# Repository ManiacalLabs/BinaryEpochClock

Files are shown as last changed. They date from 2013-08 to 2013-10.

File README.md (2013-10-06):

BinaryEpochClock
================

**THIS MAY NOT BE THE FIRMWARE THAT CAME WITH YOUR CLOCK**

*We are constantly working on improving the firmware of our kits and the firmware contained in this repository may not be the same as that which came pre-programmed on your Binary Epoch Clock Kit.*

There are a few improvements over the original v1.0 Firmware

- Based on changes suggested by [kredal](https://github.com/kredal/) there is an alternte clock face to make the clock face a little more readable. Use the following key to make it a little easier to read: http://maniacallabs.com/misc/Binary_Clock_Key.png
- A 1D Pong face is now included - It is not playable, just sit back and enjoy the game.
- Short press A in order to switch between the three clock faces

The Binary Epoch Clock is a new twist on the old binary clock idea. Instead of just showing the individual digits as binary values, it show [Unix Epoch](http://en.wikipedia.org/wiki/Unix_Epoch) time as a full 32-bit binary value. This unique timepiece will make a great addition to the desk of any computer, electronics, time, or binary geek.

It runs off of an ATMega328P which makes is both fully compatible with the Arduino IDE and easily hackable. Also built in is a DS1307 Real Time Clock chip and battery backup allowing the clock to keep accurate time even in the event of a power loss. The board includes both FTDI and ICSP headers to allow easy upload of new or modified firmware. It can be powered from any USB port or USB power adapter using the included Mini-USB cable.

The clock can bet set manually or via any 5V FTDI cable (not included) and our handy 'sync_time' script which is included in the code repository. See the [assembly and usage guide](http://maniacallabs.com/guides/binary-epoch-clock/) for instructions and a handy video detailing the manual setting procedure for the clock.

To download the firmware source and PCB design files, just click the "Download Zip" button at the right of the GitHub page.

Buy online at the [Maniacal Labs Store](http://maniacallabs.com/product/becv1/)

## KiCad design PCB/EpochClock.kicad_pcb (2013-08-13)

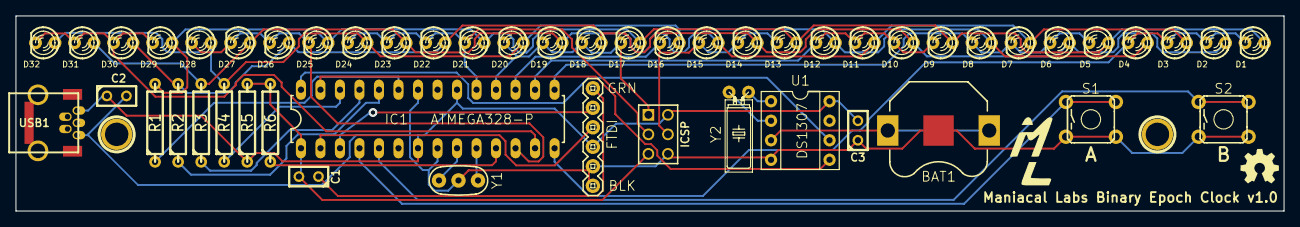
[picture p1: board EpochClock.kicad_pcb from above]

Board: 2 copper layers, 165.1 x 25.4 mm, 53 parts (0 on the bottom side), 32 nets.

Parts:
1PIN, 2PIN: P***; 1pin
BAT1: BATTERY12PTH; fixed-SparkFun-BATTCON_12MM_PTH
C1, C2, C3: 0.1uF; C1
D1, D2, D3, D4, D5, D6, D7, D8, D9, D10, D11, D12, D13, D14, D15, D16, D17, D18, D19, D20, D21, D22, D23, D24, D25, D26, D27, D28, D29, D30, D31, D32: LED; LED-3MM
IC1: ATMEGA328-P; fixed_SparkFun-DIL28-3
JP1: FTDI; SparkFun-FTDI_BASIC_fixed
P1: ICSP; pin_array_3x2
R1, R2, R3, R4: 330; R4
R5: 10K; R4
R6: 110; R4
S1: A; SparkFun-TACTILE-PTH_fixed
S2: B; SparkFun-TACTILE-PTH_fixed
U1: DS1307; fixed_SparkFun-DIL08
USB1: USB-MINI-B; USB-MINI-B-CIRCULAR_PADS
Y1: RESONATOR-16MHZ; FIXED_SparkFun-RESONATOR-PTH
Y2: CRYSTALTC38H; fixed_SparkFun-TC38H

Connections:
5VCC: C2.1, C3.2, IC1.7, IC1.20, JP1.VCC, P1.2, R5.1, U1.8, USB1.1
GND: BAT1.GND, C2.2, C3.1, IC1.8, IC1.22, JP1.CTS, JP1.GND, P1.6, S1.3, S1.4, S2.3, S2.4, U1.4, USB1.5, Y1.2
MISO: D17.2, D18.2, D19.2, D20.2, IC1.18, P1.1
MOSI: D13.2, D14.2, D15.2, D16.2, IC1.17, P1.4
unnamed: BAT1.VCC@, U1.3
unnamed: U1.1, Y2.1
unnamed: U1.2, Y2.2
unnamed: C1.1, JP1.DTR
unnamed: IC1.11, R6.1
unnamed: D1.1, D5.1, D9.1, D13.1, D17.1, D21.1, D25.1, D29.1, R1.2
unnamed: D2.1, D6.1, D10.1, D14.1, D18.1, D22.1, D26.1, D30.1, R2.2
unnamed: D3.1, D7.1, D11.1, D15.1, D19.1, D23.1, D27.1, D31.1, R3.2
unnamed: D4.1, D8.1, D12.1, D16.1, D20.1, D24.1, D28.1, D32.1, R4.2
unnamed: D9.2, D10.2, D11.2, D12.2, IC1.16
unnamed: D29.2, D30.2, D31.2, D32.2, IC1.13
unnamed: D25.2, D26.2, D27.2, D28.2, IC1.12
unnamed: IC1.24, R2.1
unnamed: IC1.23, R1.1
unnamed: D5.2, D6.2, D7.2, D8.2, IC1.15
unnamed: D1.2, D2.2, D3.2, D4.2, IC1.14
unnamed: IC1.26, R4.1
unnamed: IC1.25, R3.1
PD2: IC1.4, S1.1, S1.2
PD3: IC1.5, S2.1, S2.2
RST: C1.2, IC1.1, P1.5, R5.2, R6.2
RXI: IC1.3, JP1.RXI
SCK: D21.2, D22.2, D23.2, D24.2, IC1.19, P1.3
SCL: IC1.28, U1.6
SDA: IC1.27, U1.5
TOSC1: IC1.9, Y1.3
TOSC2: IC1.10, Y1.1
TX0: IC1.2, JP1.TXO

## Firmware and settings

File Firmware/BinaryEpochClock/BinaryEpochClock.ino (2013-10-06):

/*
Version 1.1
Copyright (c) 2013 Adam Haile, Dan Ternes & Miles Grubbs.  All right reserved.
http://ManiacalLabs.com

Many Thanks to Adafruit and Josh Ward (Kredal) for some of the code contained within.
*/

/*
Pinout Information
PC0 - PC3: Common cathode Outputs for display
PINB0-PINB5,PIND6-PIND7: Display row anodes
PC4 & PC5: SDA * SCL for I2C to RTC 
PIND0 & PIND1: RX & TX for Serial
PIND2 & PIND3: Mode & Change buttons
PIND5: Reset Enable/Disable
*/

#include <Wire.h>
#include "RTClib.h"
#include "EEPROM.h"

#include "globals.h"

//Sets the individual digits of a number 0-99
static void setTimeVals(int in, uint8_t idx) {
	setValues[idx    ] = in / 10;
	setValues[idx + 1] = in - (setValues[idx] * 10);
}

/*
Moves forward the value at curSet and constrains
to proper date/time conventions including months,
leap years, etc.
Much of this borrowed from: 
https://github.com/adafruit/TIMESQUARE-Watch/blob/master/examples/Watch/Set.pde
*/
inline void incrementSetValue()
{
	uint8_t upper, lower;
	upper = pgm_read_byte(&limit[curSet]);

	if(((curSet == SET_MO2) || (curSet == SET_D2)) && (setValues[curSet - 1] == 0)) {
		lower = 1;
	}
	else {
		lower = 0;

		if(curSet == SET_MO2) {
			if(setValues[SET_MO1] == 1) upper = 2;
		} 
		else if(curSet == SET_D2) {
			// Cap most months at 30 or 31 days as appropriate
			if(setValues[SET_D1] == 3) {
				uint8_t m = setValues[SET_MO1] * 10 + setValues[SET_MO2];
				upper = pgm_read_byte(&daysInMonth[m - 1]) % 10;
				// Finally, the dreaded leap year...
			} 
			else if((setValues[SET_D1] == 2) && (setValues[SET_MO1] == 0) &&
				(setValues[SET_MO2] == 1)) {
					uint8_t y = setValues[SET_Y1] * 10 + setValues[SET_Y2];
					if((y == 0) || (y & 3)) upper = 8; // non-leap year
			}
		} 
		else if(curSet == SET_H2) {
			if(setValues[SET_H1] == 2) upper = 3;
		}

		if(upper == lower) return;

	}

	if(++setValues[curSet] > upper) setValues[curSet] = lower;

	uint8_t m, d;
	switch(curSet) {
	case SET_MO1:
		if((setValues[SET_MO1] == 1) && (setValues[SET_MO2] > 2))
			setValues[SET_MO2] = 0;
		// Lack of break is intentional...all subsequent constraints apply.
	case SET_MO2:
		m = setValues[SET_MO1] * 10 + setValues[SET_MO2];
		if(m < 1) setTimeVals(1, SET_MO1);
	case SET_D1:
		m     = setValues[SET_MO1] * 10 + setValues[SET_MO2];
		d     = setValues[SET_D1] * 10 + setValues[SET_D2];
		upper = pgm_read_byte(&daysInMonth[m - 1]);
		if(m == 2) { // is February
			uint8_t y = setValues[SET_Y1] * 10 + setValues[SET_Y2];
			if((y > 0) && !(y & 3)) upper = 29; // is leap year
		}
		if(d > upper)  setTimeVals(upper, SET_D1);
		else if(d < 1) setTimeVals(1, SET_D1);
	case SET_H1:
	case SET_H2:
		if((setValues[SET_H1] * 10 + setValues[SET_H2]) > 23)
			setTimeVals(23, SET_H1);
	}

	timeUpdated = setChanged = true;
}

//move to next set value and wrap if needed
inline void nextSetValue()
{
	curSet++;
	if(curSet > SET_MN2) curSet = SET_Y1;
	setChanged = true;
}

//Populate setValues with the current time
inline void loadSetVals()
{
	setValues[SET_Y1] = (dt_now.year() - 2000) / 10;
	setValues[SET_Y2] = (dt_now.year() - 2000) % 10;
	setValues[SET_MO1] = dt_now.month() / 10;
	setValues[SET_MO2] = dt_now.month() % 10;
	setValues[SET_D1] = dt_now.day() / 10;
	setValues[SET_D2] = dt_now.day() % 10;
	setValues[SET_H1] = dt_now.hour() / 10;
	setValues[SET_H2] = dt_now.hour() % 10;
	setValues[SET_MN1] = dt_now.minute() / 10;
	setValues[SET_MN2] = dt_now.minute() % 10;
}

//push setValues data to the RTC
inline void adjustFromSetVal()
{
	DateTime set = DateTime(
		(setValues[SET_Y1] * 10) + setValues[SET_Y2] + 2000,
		(setValues[SET_MO1] * 10) + setValues[SET_MO2],
		(setValues[SET_D1] * 10) + setValues[SET_D2],
		(setValues[SET_H1] * 10) + setValues[SET_H2],
		(setValues[SET_MN1] * 10) + setValues[SET_MN2] ,
		0
		);

	RTC->adjust(set);
}

//Output current DateTime to serial debug
//Generally only used during testing since 
//serial is normally turned off
/*
void PrintDate(const DateTime& dt)
{
OD(dt.year()); 
OS(" "); 
OD(dt.month()); 
OS(" ");
OD(dt.day()); 
OS(" - ");
OD(dt.hour()); 
OS(":"); 
OD(dt.minute()); 
OS(":"); 
OD(dt.second());
Serial.println();
}
*/

/*
Keeping the EEPROM stuff simple. 
Only thing to save is the PWM level so 
we just read it in the 0th byte of the 
EEPROM register and then constrain to max/min
*/
inline void ReadPwmLevel()
{
	pwmLevel = EEPROM.read(0);
	if(pwmLevel <= 0 || pwmLevel > pwmMax)
		pwmLevel = pwmMax;
}

void setup()
{
	ReadPwmLevel();  

	/*
	Support for multiple RTC chip types including software only.
	RTC_METHOD is set in globals.h
	The DS3231 has nearly identical registers to the DS1307 so if using that chip there
	is no real need to update RTC_METHOD, it will just work. Besides the current hardware has 
	no place for the DS3231 (Chronodot)... maybe in the future.
	You can, however, leave out the DS1307 chip and set RTC_METHOD to USE_SOFTRTC/
	But note that there is no battery backup in this case and you will loose time if you loose power.
	*/
	if(RTC_METHOD == USE_DS1307)
		RTC = new RTC_DS1307(); 
	else if(RTC_METHOD == USE_DS3231)
		RTC = new RTC_DS3231(); 
	else
		RTC = new RTC_SOFT(DateTime(__DATE__, __TIME__));

	//init reference for time delays. used with TimeElapsed()  calls.
	//set to 0 instead of millis() so it always triggers right away the first time
	timeRef = 0;

	//Setup common cathodes as outputs
	DDRC |= (_BV(PINC0) | _BV(PINC1) | _BV(PINC2) | _BV(PINC3));
	//Setup rows as outputs
	DDRB |= (_BV(PINB0) | _BV(PINB1) | _BV(PINB2) | _BV(PINB3) | _BV(PINB4) | _BV(PINB5));
	DDRD |= (_BV(PIND6) | _BV(PIND7));

	//Set PORTD2 and PORTD3 as inputs
	DDRD &= ~(_BV(PIND2) | _BV(PIND3));
	//Enable set/change button pullups
	PORTD |= (_BV(PIND2) | _BV(PIND3));
	//Enable I2C pullups - probably not really necessary since twi.h does this for you
	PORTC |= (_BV(PINC4) | _BV(PINC5));

	//see setResetDisable(bool) for info
	DDRD &= ~(_BV(PIND5)); //Set PIND5 as input initially
	PORTD |= (_BV(PIND5)); //Set high

	//check for buttons held down at power up
	bSave = BUTTON_STATE;

	//init global time value
	dispBuf = 0;

	Wire.begin();

	//Grab current time and set to compile time if RTC is uniitialized
	dt_now = RTC->now();
	if(dt_now.unixtime() <= SECONDS_FROM_1970_TO_2000 + 60) //RTC not initialized and oscillator disabled
	{
		dt_now = DateTime(__DATE__, __TIME__);
		RTC->adjust(dt_now);
	}
	dispBuf = dt_now.unixtime();

	if(bSave != BUTTON_MASK && bSave & ~BUTTON_B)
	{
		//check again just to be sure. RTC-now() has given a bit of a delay
		bSave = BUTTON_STATE;
		if(bSave != BUTTON_MASK && bSave & ~BUTTON_B)
		{
			curState = STATE_PAUSE;
			dispBuf = 0xFFFFFFFF; 
			timeOutRef = millis();
			holdFlag = true;
		}
	}

	setInterrupts();

	Serial.begin(SERIAL_BAUD);
}

/*
Used for software disable of reset on Serial connection.
Setting PIND5 to an output through a 110 ohm resistor 
later will place 5V at low impedence on the reset pin, 
preventing it from reseting when RTS is pulsed on connection.
*/
inline void setResetDisable(bool state)
{
	if(state)
		DDRD |= (_BV(PIND5));
	else
		DDRD &= ~(_BV(PIND5));  
}  

//Setup all things interrupt related
inline void setInterrupts()
{
	//disable interrupt  timers
	cli();
	// Set up interrupt-on-change for buttons.
	EICRA = _BV(ISC10)  | _BV(ISC00);  // Trigger on any logic change
	EIMSK = _BV(INT1)   | _BV(INT0);   // Enable interrupts on pins
	bSave = BUTTON_STATE; // Get initial button state

	//Setup Display Refresh Interrupt
	TCCR1A = 0;// set entire TCCR1A register to 0
	TCCR1B = 0;// same for TCCR1B
	TCNT1  = 0;//initialize counter value to 0

	// set compare match register for 6400hz (800hz screen refresh) increments
	OCR1A = 2500;// = (16*10^6) / (1*6400) - 1 
	// turn on CTC mode
	TCCR1B |= _BV(WGM12);

	TCCR1B |= PRESCALE1_1;  
	// enable timer compare interrupt
	TIMSK1 |= _BV(OCIE1A);

	//Setup Timer2 interrupts for button handling
	//Runs at about 60Hz, which is as slow as we can go
	TCCR2A = 0;// set entire TCCR1A register to 0
	TCCR2B = 0;// same for TCCR1B
	TCNT2  = 0;//initialize counter value to 0

	// set compare match register for max
	OCR2A = 255;
	// turn on CTC mode
	TCCR2B |= _BV(WGM21);

	TCCR2B |= PRESCALE2_1024;  
	// enable timer compare interrupt
	TIMSK2 |= _BV(OCIE2A);

	//enable interrupt timers
	sei();
}

inline void endSerialSet()
{
	Serial.end();
	setResetDisable(false);
	curState = prevState;
}

//Timer2 interrupt for handling button presses
ISR(TIMER2_COMPA_vect)
{
	// Check for button 'hold' conditions
	if(bSave != BUTTON_MASK) 
	{ // button(s) held
		if(bCount >= holdMax && !holdFlag) 
		{ //held passed 1 second
			holdFlag = true;
			bCount = 0;
			if(bSave & ~BUTTON_A)
			{
				if(curState <= STATE_PONG)
				{
					prevState = curState;
					timeReady = false;
					setCancel = false;
					curState = STATE_MANUAL_SET;
					curSet = SET_Y1;
					loadSetVals();
					setChanged = true;
				}
				else if(curState == STATE_MANUAL_SET)
				{
					//set to new time
					timeReady = true;
				}
				else if(curState == STATE_PAUSE)
				{
					curState = prevState;
					ReadPwmLevel(); 
				}
				else if(curState == STATE_SERIAL_SET)
				{
					endSerialSet();
				}
			}
			else if(bSave & ~BUTTON_B)
			{
				if(curState <= STATE_PONG)
				{
					prevState = curState;
					curState = STATE_PAUSE;  
					timeOutRef = millis();  
				}
				else if(curState == STATE_PAUSE)
				{
					curState = prevState;
					ReadPwmLevel();   
				}
				else if(curState == STATE_MANUAL_SET)
				{
					setCancel = true;
				}
				else if(curState == STATE_SERIAL_SET)
				{
					endSerialSet();
				}
			}
			else
			{
				if(curState <= STATE_PONG)
				{
					prevState = curState;
					setResetDisable(true);
					Serial.begin(SERIAL_BAUD);
					_serialScan = 16; //start in middle
					_serialScanDir = false;
					timeOutRef = millis();
					curState = STATE_SERIAL_SET;
				}
				else if(curState == STATE_SERIAL_SET)
				{
					endSerialSet();
				}
				else if(STATE_PAUSE)
				{
					curState = prevState;
					ReadPwmLevel();  
				}
			}
		} 
		else bCount++; // else keep counting...
	} 
}

//Button external interrupts
ISR(INT0_vect) {
	uint8_t state = BUTTON_STATE;
	if(state == BUTTON_MASK) //both are high meaning they've been released
	{
		if(holdFlag)
		{
			holdFlag = false;
			bCount = 0;
		}
		else if(bCount > 3) //past debounce threshold
		{
			if(bSave & ~BUTTON_A)
			{
				if(curState == STATE_MANUAL_SET)
				{
					nextSetValue();
				}
				else if(curState == STATE_FULL_BINARY)
				{
					curState = STATE_SUB_BINARY;
				}
				else if(curState == STATE_SUB_BINARY)
				{
					resetPongBall();
					_pongLScore = _pongRScore = 0;
					curState = STATE_PONG;
				}
				else if(curState == STATE_PONG)
				{
					curState = STATE_FULL_BINARY;
				}
			}
			else if(bSave & ~BUTTON_B)
			{
				if(curState <= STATE_PONG)
				{
					//Change PWM level
					pwmLevel--;
					if(pwmLevel <= 0 || pwmLevel > pwmMax)
						pwmLevel = pwmMax;

					EEPROM.write(0, pwmLevel);
				}
				else if(curState == STATE_MANUAL_SET)
				{
					incrementSetValue();
				}
			}
		}
		bCount = 0;
	}
	else if(state != bSave) {
		bCount = 0; 
	}

	bSave = state;
}

//Use the same handler for both INT0 and INT1 interrupts
ISR(INT1_vect, ISR_ALIASOF(INT0_vect));

/*
Where the magic happens. All the multiplexing is done here.
We start by disabling all the "columns" which actually means turning them to high
since this is common ground. 
If in serial set mode we do a larson scanner instead of show the time.
Otherwise set the states of each of the 4 LEDs in each row and then finally
re-enable the column for this pass through the loop.
It requires 8 passes (1 per column) through this to update the display once.
As this is called at 6400Hz, we update the display fully at 800Hz.
*/
volatile uint8_t col = 0, row = 0;
volatile uint8_t scan_low = 0, scan_high = 0;
#define SCAN_WIDTH 2
ISR(TIMER1_COMPA_vect)
{
	//Turn all columns off (High is off in this case since it's common cathode)
	PORTB |= (_BV(PINB0) | _BV(PINB1) | _BV(PINB2) | _BV(PINB3) | _BV(PINB4) | _BV(PINB5));
	PORTD |= (_BV(PIND6) | _BV(PIND7));

	if(curState == STATE_SERIAL_SET)
	{
		scan_low = _serialScan >= SCAN_WIDTH ? _serialScan - SCAN_WIDTH : 0;
		scan_high = _serialScan <= (31 - SCAN_WIDTH) ? _serialScan + SCAN_WIDTH : 31;
		byte _scanOffset = 0;
		byte _curStep = 0; 

		//set the 4 rows
		for(row=0; row<4; row++)
		{
			_curStep = (row + (col * 4));

			if(_curStep < _serialScan) _scanOffset = (_serialScan - _curStep);
			else if(_curStep > _serialScan) _scanOffset = (_curStep - _serialScan);
			else _scanOffset = 0;

			if((_curStep >= scan_low && _curStep <= scan_high) &&
				(_serialScanStep < scanLevels[_scanOffset]))
				PORTC |= _BV(row);
			else
				PORTC &= ~_BV(row);
		}

		//Enable the current column
		if(col < 6)
			PORTB &= ~_BV(col);
		else
			PORTD &= ~_BV(col);
	}
	else
	{
		if(pwmStep < pwmLevel)
		{
			//set the 4 rows
			for(row=0; row<4; row++)
			{
				if(dispBuf & (1UL << (row + (col * 4))))
					PORTC |= _BV(row);
				else
					PORTC &= ~_BV(row);
			} 

			//Enable the current column
			if(col < 6)
				PORTB &= ~_BV(col);
			else
				PORTD &= ~_BV(col);
		}
	}

	col++;
	if(col == 8)
	{ 
		col = 0;
		pwmStep++;
		if(pwmStep == pwmMax)
			pwmStep = 0;

		if(curState == STATE_SERIAL_SET)
		{
			_serialScanStep++;
			if(_serialScanStep == 10) _serialScanStep = 0; 
		}
	}
}

//Helper for time delays without actually pausing execution
bool TimeElapsed(unsigned long ref, unsigned long wait)
{
	unsigned long now = millis();

	if(now < ref || ref == 0) //for the 50 day rollover or first boot
		return true;  

	if((now - ref) > wait)
		return true;
	else
		return false;
}

/*
Get time from serial connection
Time data is just the letter 't' followed by 4 bytes 
representing a unix epoch 32-bit time stamp. 
The time is assumed to already be adjusted for local 
time zone and DST by the sending computer as RTC does not 
store time as UTC.
*/
bool getPCTimeSync()
{
	bool result = false;
	if(Serial.available() >= SYNC_LEN)
	{
		byte buf[5];
		memset(buf, 0, 5);
		Serial.readBytes((char *)buf, 5);
		if(buf[0] == SYNC_HEADER)
		{
			uint32_t t = 0;
			memcpy(&t, buf+1, 4);
			RTC->adjust(DateTime(t));
			Serial.write(42); //Writes out to confirm we got it (sends as a *)
			Serial.flush();
			result = true;
			while(Serial.available()) Serial.read(); //clear the bufer
			Serial.end();
			setResetDisable(false);
		}
		else if(buf[0] == GET_HEADER)
		{
			dt_now = RTC->now();
			uint32_t time = dt_now.unixtime();
			memset(buf, 0, 5);
			buf[0] = SYNC_HEADER;
			memcpy(buf+1, &time, 4);
			Serial.write(buf, 5);
			Serial.flush();
			result = true;
		}
	}

	return result;
}

inline void resetPongBall() 
{ 
	randomSeed(millis());
	_pongBall = random(2) ? 15 : 16; 
	_pongDir = _pongBall > 15;
	_pongPaddles = (1UL << 31) | (1UL << 0);
}

inline void randomPongPaddles()
{

	switch ( random(4) % 4)
	{
	case 0:
		_pongPaddles = 0;
		break;
	case 1: 
		_pongPaddles = (1UL << 31);
		break;
	case 2: 
		_pongPaddles = (1UL << 0);
		break;
	case 3: 
		_pongPaddles = (1UL << 31) | (1UL << 0);
		break;
	}
}

/*
The main program state machine.
Most of the time this will just be updating the time every 500ms
(1000ms can cause noticable jumps if program execution takes longer than normal).
*/
void loop()
{

	if(curState == STATE_FULL_BINARY)
	{
		if(TimeElapsed(timeRef, 500))
		{
			timeRef = millis();
			dt_now = RTC->now();
			dispBuf = dt_now.unixtime();
		}
	}
	//many thanks to Josh Ward for this new clock "face" that's a little more readable
	//https://github.com/kredal/
	//Use the following "key" for reading in this mode: http://maniacallabs.com/misc/Binary_Clock_Key.png
	//Tapping A will now switch between the modes
	else if(curState == STATE_SUB_BINARY)
	{
		if(TimeElapsed(timeRef, 500))
		{
			timeRef = millis();
			dt_now = RTC->now();

			sbVals[0] = dt_now.second();
			sbVals[1] = dt_now.minute();
			sbVals[2] = dt_now.hour();
			sbVals[3] = dt_now.day();
			sbVals[4] = dt_now.month();
			sbVals[5] = dt_now.year() - 2000;

			int i = 0;
			for(int i=0; i<=5; i++)
			{
				for(sbCurBit=0; sbCurBit <= sbBits[i]; sbCurBit++)
				{
					if(sbVals[i]  & (1UL << sbCurBit))
						dispBuf |= (1UL << sbCurBit + sbOffsets[i]);
					else
						dispBuf &= ~(1UL << sbCurBit + sbOffsets[i]);
				}
			}
		}
	}
	else if(curState == STATE_PONG)
	{
		if(TimeElapsed(timeRef, _pongTimeout))
		{
			timeRef = millis();
			if(_pongShowScore)
			{
				_pongShowScore = false;
				_pongTimeout = PONG_TIMEOUT;
				if(_pongLScore >= 16 || _pongRScore >= 16)
				{
					_pongLScore = _pongRScore = 0;
				}
			}

			if(_pongDir)
			{
				if(_pongBall == 30)
				{
					if(_pongPaddles & (1UL << 31))
					{
						_pongDir = false;
						randomPongPaddles();
					}
					else
					{
						_pongRScore++;
						_pongShowScore = true;
						resetPongBall();
					}
				}
			}
			else
			{
				if(_pongBall == 1)
				{
					if(_pongPaddles & (1UL << 0))
					{
						_pongDir = true; 
						randomPongPaddles();
					}
					else
					{
						_pongLScore++;
						_pongShowScore = true;
						resetPongBall();
					}
				}
			}

			_pongBall += _pongDir ? 1 : -1;

			if(_pongShowScore)
			{
				_pongTimeout = 1000;
				dispBuf = (((1UL << 32) - 1) - ((1UL << (32 - _pongLScore)) - 1)) + ((1UL << _pongRScore) - 1);
			}
			else
			{
				dispBuf = _pongPaddles | (1UL << _pongBall);
			}
		}
	}
	else if(curState == STATE_PAUSE)
	{
		if(TimeElapsed(timeOutRef, 600000))
		{
			curState = prevState;
		}
		else
		{
			if(TimeElapsed(timeRef, 50))
			{
				timeRef = millis();
				if(pwmLevel == pwmMax) fadeDir = false;
				else if(pwmLevel == 1) fadeDir = true;
				pwmLevel += (fadeDir ? 1 : -1);
			}
		}
	}
	else if(curState == STATE_MANUAL_SET)
	{
		if(timeReady)
		{
			adjustFromSetVal();
			curState = prevState; 
		}
		else if(setChanged)
		{
			setChanged = false;
			uint32_t temp = 0;
			if(setValues[curSet])
				temp += ((1UL << setValues[curSet]) - 1);

			temp |= (1UL << (31 - curSet));   
			dispBuf = temp;
		}
		else if(setCancel)
		{
			curState = prevState;
		}

	}
	else if(curState == STATE_SERIAL_SET)
	{
		if(TimeElapsed(timeOutRef, 30000))
		{
			Serial.end();
			setResetDisable(false);
			curState = prevState;
		}
		else
		{
			if(TimeElapsed(timeRef, 40))
			{
				timeRef = millis();
				if(_serialScan == 31) _serialScanDir = false;
				else if(_serialScan == 0) _serialScanDir = true;
				_serialScan += (_serialScanDir ? 1 : -1);
			}

			//check for serial data for time sync
			if(getPCTimeSync())
				curState = prevState;
		}
	}
}

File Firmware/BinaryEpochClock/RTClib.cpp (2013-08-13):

// Original code by JeeLabs http://news.jeelabs.org/code/
// Released to the public domain! Enjoy!

// Maniacal Labs version based on heavily modified version of above from:
// https://github.com/MrAlvin/RTClib

#include <Wire.h>
#include <avr/pgmspace.h>
#include "RTClib.h"

#define DS1307_ADDRESS 0x68
#define DS3231_ADDRESS 0x68

#define SECONDS_PER_DAY 86400L

#if (ARDUINO >= 100)
 #include <Arduino.h> // capital A so it is error prone on case-sensitive filesystems
#else
 #include <WProgram.h>
#endif

int i = 0; //The new wire library needs to take an int when you are sending for the zero register


////////////////////////////////////////////////////////////////////////////////
// utility code, some of this could be exposed in the DateTime API if needed

const uint8_t daysInMonth [] PROGMEM = { 31,28,31,30,31,30,31,31,30,31,30,31 }; //has to be const or compiler compaints

// number of days since 2000/01/01, valid for 2001..2099
static uint16_t date2days(uint16_t y, uint8_t m, uint8_t d) {
    if (y >= 2000)
        y -= 2000;
    uint16_t days = d;
    for (uint8_t i = 1; i < m; ++i)
        days += pgm_read_byte(daysInMonth + i - 1);
    if (m > 2 && y % 4 == 0)
        ++days;
    return days + 365 * y + (y + 3) / 4 - 1;
}

static long time2long(uint16_t days, uint8_t h, uint8_t m, uint8_t s) {
    return ((days * 24L + h) * 60 + m) * 60 + s;
}

////////////////////////////////////////////////////////////////////////////////
// DateTime implementation - ignores time zones and DST changes
// NOTE: also ignores leap seconds, see http://en.wikipedia.org/wiki/Leap_second

DateTime::DateTime (uint32_t t) {
  t -= SECONDS_FROM_1970_TO_2000;    // bring to 2000 timestamp from 1970

    ss = t % 60;
    t /= 60;
    mm = t % 60;
    t /= 60;
    hh = t % 24;
    uint16_t days = t / 24;
    uint8_t leap;
    for (yOff = 0; ; ++yOff) {
        leap = yOff % 4 == 0;
        if (days < 365 + leap)
            break;
        days -= 365 + leap;
    }
    for (m = 1; ; ++m) {
        uint8_t daysPerMonth = pgm_read_byte(daysInMonth + m - 1);
        if (leap && m == 2)
            ++daysPerMonth;
        if (days < daysPerMonth)
            break;
        days -= daysPerMonth;
    }
    d = days + 1;
}

DateTime::DateTime (uint16_t year, uint8_t month, uint8_t day, uint8_t hour, uint8_t min, uint8_t sec) {
    if (year >= 2000)
        year -= 2000;
    yOff = year;
    m = month;
    d = day;
    hh = hour;
    mm = min;
    ss = sec;
}

static uint8_t conv2d(const char* p) {
    uint8_t v = 0;
    if ('0' <= *p && *p <= '9')
        v = *p - '0';
    return 10 * v + *++p - '0';
}

// A convenient constructor for using "the compiler's time":
//   DateTime now (__DATE__, __TIME__);
// NOTE: using PSTR would further reduce the RAM footprint
DateTime::DateTime (const char* date, const char* time) {
    // sample input: date = "Dec 26 2009", time = "12:34:56"
    yOff = conv2d(date + 9);
    // Jan Feb Mar Apr May Jun Jul Aug Sep Oct Nov Dec 
    switch (date[0]) {
        case 'J': m = date[1] == 'a' ? 1 : m = date[2] == 'n' ? 6 : 7; break;
        case 'F': m = 2; break;
        case 'A': m = date[2] == 'r' ? 4 : 8; break;
        case 'M': m = date[2] == 'r' ? 3 : 5; break;
        case 'S': m = 9; break;
        case 'O': m = 10; break;
        case 'N': m = 11; break;
        case 'D': m = 12; break;
    }
    d = conv2d(date + 4);
    hh = conv2d(time);
    mm = conv2d(time + 3);
    ss = conv2d(time + 6);
}

uint8_t DateTime::dayOfWeek() const {    
    uint16_t day = date2days(yOff, m, d);
    return (day + 6) % 7; // Jan 1, 2000 is a Saturday, i.e. returns 6
}

uint32_t DateTime::unixtime(void) const {
  uint32_t t;
  uint16_t days = date2days(yOff, m, d);
  t = time2long(days, hh, mm, ss);
  t += SECONDS_FROM_1970_TO_2000;  // seconds from 1970 to 2000

  return t;
}

////////////////////////////////////////////////////////////////////////////////
// By Coobro
const char* months[] = { "Jan", "Feb", "Mar", "Apr", "May", "Jun", "Jul", "Aug", "Sep", "Oct", "Nov", "Dec" };

// as a string
char* DateTime::toString(char* buf, int maxlen) const
{
    snprintf(buf,maxlen,"%s %02u %04u %02u:%02u:%02u",
             months[m-1],
             d,
             2000 + yOff,
             hh,
             mm,
             ss
            );
    return buf;
}

void DateTime::operator+=(uint32_t additional)
{
    DateTime after = DateTime( unixtime() + additional );
    *this = after;
}

///////////////////////////////////////////////////////////////////////////////
// BCD conversion tools

static uint8_t bcd2bin (uint8_t val) { return val - 6 * (val >> 4); }
static uint8_t bin2bcd (uint8_t val) { return val + 6 * (val / 10); }

///////////////////////////////////////////////////////////////////////////////
// Arduino 1.0 addition

#if (ARDUINO >= 100)
	#define WW_  Wire.write
	#define WR_  Wire.read
#else
	#define WW_  Wire.send
	#define WR_  Wire.receive
#endif	

#if ARDUINO < 100
#define SEND(x) send(x) 
#define RECEIVE(x) receive(x) 
#else
#define SEND(x) write(static_cast<uint8_t>(x))
#define RECEIVE(x) read(x)
#endif


////////////////////////////////////////////////////////////////////////////////
// RTC_DS1307 implementation

uint8_t RTC_DS1307::begin(void) {
  return 1;
}


uint8_t RTC_DS1307::isrunning(void) {
  Wire.beginTransmission(DS1307_ADDRESS);
  WW_(i);	
  Wire.endTransmission();

  Wire.requestFrom(DS1307_ADDRESS, 1);
  uint8_t ss = WR_();
  return !(ss>>7);
}

void RTC_DS1307::adjust(const DateTime& dt) {
    Wire.beginTransmission(DS1307_ADDRESS);
    WW_(i);
    WW_(bin2bcd(dt.second()));
    WW_(bin2bcd(dt.minute()));
    WW_(bin2bcd(dt.hour()));
    WW_(bin2bcd(0));
    WW_(bin2bcd(dt.day()));
    WW_(bin2bcd(dt.month()));
    WW_(bin2bcd(dt.year() - 2000));
    WW_(i);
    Wire.endTransmission();
}

DateTime RTC_DS1307::now() {
  Wire.beginTransmission(DS1307_ADDRESS);
  WW_(i);	
  Wire.endTransmission();
  
  Wire.requestFrom(DS1307_ADDRESS, 7);
  uint8_t ss = bcd2bin(WR_() & 0x7F);
  uint8_t mm = bcd2bin(WR_());
  uint8_t hh = bcd2bin(WR_());
  WR_();
  uint8_t d = bcd2bin(WR_());
  uint8_t m = bcd2bin(WR_());
  uint16_t y = bcd2bin(WR_()) + 2000;
  
  return DateTime (y, m, d, hh, mm, ss);
}

uint8_t RTC_DS1307::readMemory(uint8_t offset, uint8_t* data, uint8_t length) {
  uint8_t bytes_read = 0;

  Wire.beginTransmission(DS1307_ADDRESS);
  WW_(0x08 + offset);
  Wire.endTransmission();
  
  Wire.requestFrom((uint8_t)DS1307_ADDRESS, (uint8_t)length);
  while (Wire.available() > 0 && bytes_read < length) {
    data[bytes_read] = WR_();
    bytes_read++;
  }

  return bytes_read;
}

uint8_t RTC_DS1307::writeMemory(uint8_t offset, uint8_t* data, uint8_t length) {
  uint8_t bytes_written;

  Wire.beginTransmission(DS1307_ADDRESS);
  WW_(0x08 + offset);
#if (ARDUINO >= 100)
  bytes_written =  WW_(data, length);
  Wire.endTransmission();
  return bytes_written;
#else
  WW_(data, length);
  Wire.endTransmission();
  return length;
#endif  
}
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

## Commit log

2013-08-13 initial GitHub commit of firmware and pcb designs
    [EpochClock.dsn, EpochClock.kicad_pcb, EpochClock.sch]
2013-08-31 Update BinaryEpochClock.ino
    Replaced the very simple STATE_NONE with the Josh Rox mod, making a semi-readable clock.
    [BinaryEpochClock.ino]
2013-08-31 Update BinaryEpochClock.ino
    fixed time constructs.
    [BinaryEpochClock.ino]
2013-08-31 Few changes from Josh's code and adding short tap of A to change modes
    [BinaryEpochClock.ino, globals.h]
